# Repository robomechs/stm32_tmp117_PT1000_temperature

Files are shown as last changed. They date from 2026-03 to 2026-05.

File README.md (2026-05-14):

# STM32F103C8 BluePill USB Temperature Monitor

This project is a USB-connected temperature measurement setup for the STM32F103C8T6 **BluePill** board.

It combines:

- a **PT1000** analog sensor read by the STM32 ADC,
- a **TMP117** digital sensor connected over I2C,
- direct **USB CDC** communication from the BluePill to the PC,
- and a desktop **Python viewer** for live plotting, software filtering, and CSV logging.

The board connects to the PC **directly over USB** and enumerates as a virtual COM port. No separate USB-UART adapter is required.

## Project Overview

The firmware runs on an STM32F103C8-based BluePill board and streams temperature data over USB CDC.

Current default behavior:

- **PT1000** is sampled through the ADC at **1 kHz**
- the PT1000 ADC path is smoothed in firmware with a fixed-point LPF at about **10 Hz**
- PT1000 temperature is transmitted over USB at **20 Hz**
- **TMP117** is still polled in firmware at **20 Hz**
- TMP117 is **not filtered in firmware**
- TMP117 is **not sent by default**, but the code already supports switching to TMP117-only or both-sensors output

On the PC side, the included viewer can:

- connect to the USB virtual COM port,
- display live values,
- plot incoming data,
- apply a **software LPF** in the GUI,
- show or hide raw and filtered traces independently,
- and log data to CSV.

## Hardware

### Target MCU board

- **STM32F103C8T6 BluePill**

## Measurement Ranges

Reference specifications used here:

- [PT106052 / SA10200542 PT1000 listing](https://www.tme.com/ca/en/details/pt106052/temp-sensors-resistance-thermometers/cyntec-co-ltd/sa10200542/)
- [TI TMP117 product page](https://www.ti.com/product/TMP117)

### PT1000 channel

The PT1000 element used for this project is PT106052 / SA10200542 style: `Pt1000`, class B `0.12 %`, `3850 ppm/C`, with a specified operating range of approximately **-50 C to +500 C**.

This is the intended practical measurement range for the PT1000 channel.

The firmware uses a simple linear PT1000 approximation:

```text
R(T) = R0 * (1 + 0.00385 * T)
```

So the conversion is intentionally simple and integer-friendly for STM32F103. For better absolute accuracy across the full `-50...500 C` span, the next improvement would be a calibrated table or Callendar-Van Dusen conversion.

With the current divider value, the PT1000 range maps well into the 12-bit ADC input range:

| Temperature | Approx. PT1000 resistance | Approx. ADC code | Approx. ADC voltage at 3.3 V |
| --- | ---: | ---: | ---: |
| `-50 C` | `807.5 Ohm` | `2749` | `2.22 V` |
| `0 C` | `1000.0 Ohm` | `2550` | `2.06 V` |
| `25 C` | `1096.3 Ohm` | `2460` | `1.98 V` |
| `100 C` | `1385.0 Ohm` | `2226` | `1.79 V` |
| `500 C` | `2925.0 Ohm` | `1477` | `1.19 V` |

The ADC itself has much wider mathematical headroom, but the useful documented PT1000 range should be treated as **-50 C to +500 C** unless the sensor, mounting, wiring, and calibration are validated outside that range.

### TMP117 channel

The TMP117 channel is intended for the TMP117 operating range: **-55 C to +150 C**.

In the current firmware, TMP117 is polled at `20 Hz`, but the default USB stream sends PT1000 only. TMP117 output can be enabled in firmware with `USB_STREAM_MODE_TMP117` or `USB_STREAM_MODE_BOTH`.

### PT1000 connection

The PT1000 is connected as a simple divider from `3.3 V`:

- top resistor: **PT1000**
- bottom resistor: **1.65 kOhm**
- divider midpoint: `PA0 / ADC1_IN0`

Divider:

`3.3V -> PT1000 -> PA0 -> 1.65k -> GND`

The `1.65 kOhm` resistor was chosen to place the expected `-50...500 C` PT1000 resistance range comfortably inside the ADC range while keeping useful sensitivity over the whole span. It is not a common single resistor value, so it can be made from **two 3.3 kOhm resistors in parallel**:

```text
3.3k || 3.3k = 1.65k
```

The divider resistor is used directly by the firmware conversion. In [main.c](TMP117_stm32f103c8/Core/Src/main.c), the value is defined as `PT1000_BOTTOM_RESISTOR_MOHM`. It is stored in milliohms; the current nominal value is `1650000`, meaning `1650.000 Ohm`.

If better absolute accuracy is needed, measure the actual parallel resistance and put that value into `PT1000_BOTTOM_RESISTOR_MOHM` in milliohms.

If the PT1000 and the `1.65 kOhm` resistor are physically swapped during assembly, the firmware can be switched without rewiring. Set `PT1000_DIVIDER_PT1000_ON_TOP` to `0` in [main.c](TMP117_stm32f103c8/Core/Src/main.c). Default is `1`, meaning `3.3V -> PT1000 -> PA0 -> 1.65k -> GND`.

Swapping the divider mostly reverses the ADC slope. Sensitivity and self-heating are nearly the same because the same two resistors are still in series. With the correct define, measurements remain valid; with the wrong define, the temperature will be badly wrong.

### TMP117 connection

- `PB6` -> `I2C1_SCL`
- `PB7` -> `I2C1_SDA`
- default I2C address: `0x48`

Additional pins:

- `PB8` -> TMP117 `ALERT` input with external pull-up
- `PB9` -> TMP117 `ADD0` output, held low with external pull-down

### USB connection

The firmware uses the STM32 USB CDC device interface and appears on the PC as a virtual COM port.

Project-specific USB notes:

- `PB5` is used for the external USB reconnect/reset wiring
- D+ has an external `1.5 kOhm` pull-up to `3.3 V`
- the firmware generates a reconnect pulse during startup so the BluePill re-enumerates cleanly over USB

## Firmware

Firmware source is in:

- [TMP117_stm32f103c8](TMP117_stm32f103c8)

Main application file:

- [main.c](TMP117_stm32f103c8/Core/Src/main.c)

### Firmware data path

#### PT1000 path

- sampled by `ADC1` on `PA0`
- ADC timing tuned for slower, quieter sampling
- sampled at **1 kHz**
- filtered in firmware with fixed-point arithmetic
- converted to temperature in degrees Celsius
- sent over USB at **20 Hz**

#### TMP117 path

- read over `I2C1`
- polled at **20 Hz**
- kept in firmware for reference / comparison
- **not filtered in firmware**
- **not streamed by default**

### Default USB output

Current default build sends only PT1000:

```text
PT1000=24.875 C
```

With line ending on the wire:

```text
PT1000=24.875 C\r\n
```

### Other firmware output modes

The firmware can also send:

- TMP117 only
- both PT1000 and TMP117 in one line

These modes are selected in [main.c](TMP117_stm32f103c8/Core/Src/main.c) by the `USB_STREAM_MODE` define.

Typical options in the code:

- `USB_STREAM_MODE_PT1000`
- `USB_STREAM_MODE_TMP117`
- `USB_STREAM_MODE_BOTH`

Example combined line:

```text
PT1000=24.875 C TMP117=24.937 C
```

## Desktop Viewer

Viewer file:

- [temperature_viewer.pyw](temperature_viewer.pyw)

The viewer is intended for direct use with the BluePill USB CDC connection.

### Viewer features

- automatic COM port refresh
- connect/disconnect control
- compact COM names such as `COM3`
- live readout for PT1000 and TMP117
- plot view for one sensor or both sensors
- separate **Show raw** and **Show filtered** checkboxes
- software LPF modes:
  - `Off`
  - `EMA`
  - `SMA`
- adjustable visible X-axis window
- `Follow latest` mode
- `Auto Y`
- `Show all`
- `Reset view`
- `Clear plot`
- `Help` button with built-in usage notes
- CSV logging

### Important note about filtering

There are two different filtering layers in this project:

1. **Firmware PT1000 LPF**
   - applied on the MCU to the ADC path
   - fixed-point
   - currently about `10 Hz`

2. **Viewer software LPF**
   - applied inside the PC application
   - tunable in the UI
   - available for display, comparison, and CSV logging

TMP117 currently has **no firmware LPF**. In the viewer, TMP117 can still be filtered in software for visualization.

### Viewer input formats

The viewer accepts the current labeled firmware stream, for example:

```text
PT1000=24.875 C
```

or:

```text
PT1000=24.875 C TMP117=24.937 C
```

It also keeps compatibility with older single-value lines through the `Single line` selector in the UI.

### CSV logging

The viewer can save CSV with these columns:

```text
timestamp_s,pt1000_raw_c,pt1000_filtered_c,tmp117_raw_c,tmp117_filtered_c
```

## Python Requirements

The viewer uses:

- Python 3
- `PyQt6`
- `pyqtgraph`
- `pyserial`

Example install command:

```bash
pip install PyQt6 pyqtgraph pyserial
```

Run the viewer with:

```bash
py temperature_viewer.pyw
```

On Windows, you can also launch the `.pyw` file directly.

## Building the Firmware

This firmware project is based on an STM32CubeIDE-generated STM32F103 project.

Main project file:

- [TMP117_stm32f103c8.ioc](TMP117_stm32f103c8/TMP117_stm32f103c8.ioc)

### Recommended build flow

1. Open the project in **STM32CubeIDE**
2. Open the `.ioc` if needed
3. Let CubeIDE regenerate project files if required
4. Build the project for the **STM32F103C8T6 BluePill**
5. Flash it with your usual ST-Link workflow

### Command-line build

If the local `Debug` build directory already exists, the project can also be built with:

```bash
make -C TMP117_stm32f103c8/Debug all
```

Note:

- `Debug/` is gitignored
- in a fresh clone, it is normal to open the project in CubeIDE first so the build files are present locally

## Repository Layout

- [TMP117_stm32f103c8](TMP117_stm32f103c8) - STM32 firmware project
- [temperature_viewer.pyw](temperature_viewer.pyw) - desktop GUI viewer
- [TMP117_PCB](TMP117_PCB) - KiCad PCB project

Inside the PCB folder:

- KiCad source project is in [tmp117](TMP117_PCB/tmp117)
- [bom](TMP117_PCB/tmp117/bom) contains BOM-related output
- [manuf](TMP117_PCB/tmp117/manuf) contains manufacturing files

## Practical Usage

Typical workflow:

1. Flash the firmware to the **BluePill**
2. Connect the board to the PC via **USB**
3. Wait for the USB CDC virtual COM port to appear
4. Start [temperature_viewer.pyw](temperature_viewer.pyw)
5. Select the COM port
6. Click `Connect`
7. View live temperature, tune software LPF, and log CSV if needed

## Notes

- The repository ignores generated build outputs, Python cache files, KiCad local history, and KiCad backup archives.
- The current default USB stream is PT1000-only, which keeps the USB output simple for the viewer and logging workflow.
- TMP117 acquisition is still active in firmware, so enabling dual-sensor output later is straightforward.

## PT1000 Wiring Quick Reference

Use this connection for the PT1000 divider:

```text
BluePill 3V3 -> PT1000 -> PA0 / ADC1_IN0 -> 1.65k -> GND
```

This is the default firmware setting:

```c
#define PT1000_DIVIDER_PT1000_ON_TOP 1U
```

If the parts are swapped:

```text
BluePill 3V3 -> 1.65k -> PA0 / ADC1_IN0 -> PT1000 -> GND
```

use this firmware setting:

```c
#define PT1000_DIVIDER_PT1000_ON_TOP 0U
```

The bottom resistor may be either:

```text
single 1.65k resistor
```

or:

```text
two 3.3k resistors in parallel
```

Keep the ADC node connected only to `PA0`, the PT1000, and the bottom resistor. Do not connect the divider to `5 V`; the firmware assumes `3.3 V` ADC reference behavior.

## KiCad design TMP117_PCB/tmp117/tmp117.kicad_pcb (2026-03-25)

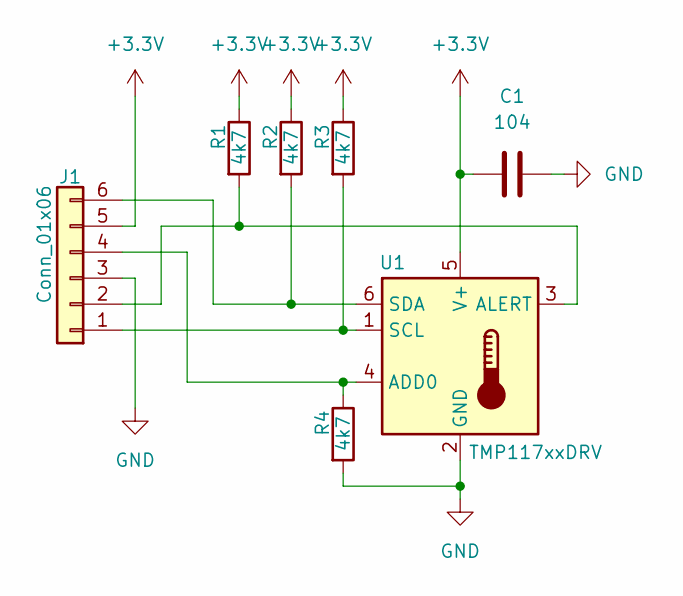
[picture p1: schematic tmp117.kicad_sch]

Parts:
C1: 104; C_1206_3216Metric
J1: Conn_01x06; Zhaoxing_VH_ZX-VH3.96-6PLT_1x06-1MP_P3.96mm_Vertical
R1, R2, R3, R4: 4k7; R_0805_2012Metric_Pad1.20x1.40mm_HandSolder
U1: TMP117xxDRV; WSON-6-1EP_2x2mm_P0.65mm_EP1x1.6mm

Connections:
+3.3V: C1.1, J1.5, R1.1, R2.1, R3.1, U1.5 (V+)
GND: C1.2, J1.3, R4.2, U1.2 (GND)
unnamed: J1.1, R3.2, U1.1 (SCL)
unnamed: J1.2, R1.2, U1.3 (ALERT)
unnamed: J1.4, R4.1, U1.4 (ADD0)
unnamed: J1.6, R2.2, U1.6 (SDA)

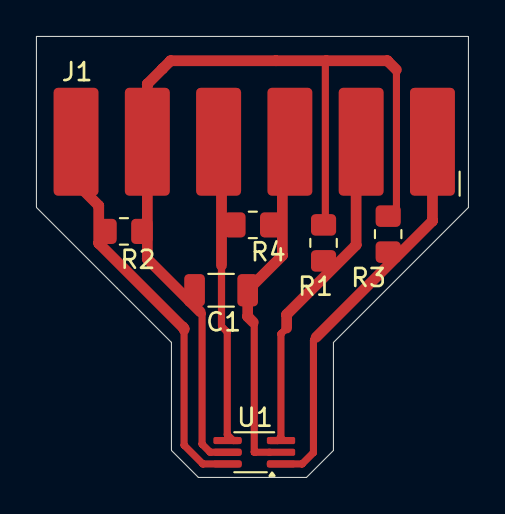
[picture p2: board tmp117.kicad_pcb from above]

Board: 2 copper layers, 24.0 x 24.5 mm, 7 parts (0 on the bottom side), 6 nets.

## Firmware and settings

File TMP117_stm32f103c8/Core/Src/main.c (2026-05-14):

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
/* Includes ------------------------------------------------------------------*/
#include "main.h"

/* USER CODE BEGIN Includes */
#include "usb_device.h"
#include "usbd_cdc_if.h"
#include <limits.h>
#include <stdio.h>

/* USER CODE END Includes */

/* USER CODE BEGIN PD */
#define TMP117_I2C_ADDRESS     (0x48U << 1)
#define TMP117_REG_TEMPERATURE 0x00U
#define TMP117_I2C_TIMEOUT_MS  50U
#define USB_RECONNECT_DELAY_MS 50U

#define PT1000_FILTER_SAMPLE_RATE_HZ        1000U
#define PT1000_USB_OUTPUT_RATE_HZ           20U
#define PT1000_OUTPUT_TICKS                 (PT1000_FILTER_SAMPLE_RATE_HZ / PT1000_USB_OUTPUT_RATE_HZ)
#define PT1000_FILTER_ALPHA_Q15             1937U /* fc ~= 10 Hz at fs = 1 kHz */
#define PT1000_ADC_FULL_SCALE_COUNTS        4095U
#define PT1000_DIVIDER_PT1000_ON_TOP        1U /* 1: 3V3-PT1000-A0-1.65k-GND, 0: 3V3-1.65k-A0-PT1000-GND */
#define PT1000_BOTTOM_RESISTOR_MOHM         1650000LL
#define PT1000_REFERENCE_RESISTANCE_MOHM    1000000LL
#define PT1000_ALPHA_PPM_PER_C              3850LL

#define USB_STREAM_MODE_PT1000              0U
#define USB_STREAM_MODE_TMP117              1U
#define USB_STREAM_MODE_BOTH                2U
#define USB_STREAM_MODE                     USB_STREAM_MODE_PT1000

/* USER CODE END PD */

ADC_HandleTypeDef hadc1;
I2C_HandleTypeDef hi2c1;
TIM_HandleTypeDef htim2;

/* USER CODE BEGIN PV */
static volatile uint8_t usb_frame_due = 0U;
static volatile uint8_t tmp117_sample_due = 0U;
static volatile uint16_t pt1000_filtered_adc_counts = 0U;
static uint8_t usb_tx_pending = 0U;
static uint8_t usb_tx_buffer[96];
static uint16_t usb_tx_length = 0U;
static uint8_t pt1000_filter_initialized = 0U;
static int32_t pt1000_filter_state_q15 = 0;
static int32_t latest_pt1000_milli_c = 0;
static int32_t latest_tmp117_milli_c = 0;
static uint8_t latest_tmp117_valid = 0U;

/* USER CODE END PV */

void SystemClock_Config(void);
static void MX_ADC1_Init(void);
static void MX_GPIO_Init(void);
static void MX_I2C1_Init(void);
static void MX_TIM2_Init(void);
/* USER CODE BEGIN PFP */
static void USB_ReconnectPulse(void);
static HAL_StatusTypeDef TMP117_ReadRawTemperature(int16_t *raw_temperature);
static int32_t TMP117_RawToMilliC(int16_t raw_temperature);
static HAL_StatusTypeDef PT1000_SampleAndFilter(void);
static int32_t PT1000_AdcToMilliC(uint16_t adc_counts);
static void QueuePT1000Frame(void);
static void QueueTMP117Frame(void);
static void QueueBothTemperaturesFrame(void);
static void QueueSelectedTemperatureFrame(void);
static void ServiceTemperatureStream(void);

/* USER CODE END PFP */

/**
  * @brief  The application entry point.
  * @retval int
  */
int main(void)
{

  /* MCU Configuration--------------------------------------------------------*/

  /* Reset of all peripherals, Initializes the Flash interface and the Systick. */
  HAL_Init();

  /* Configure the system clock */
  SystemClock_Config();

  /* Initialize all configured peripherals */
  MX_GPIO_Init();
  MX_ADC1_Init();
  MX_I2C1_Init();
  MX_TIM2_Init();
  /* USER CODE BEGIN 2 */
  if (HAL_ADCEx_Calibration_Start(&hadc1) != HAL_OK)
  {
    Error_Handler();
  }

  USB_ReconnectPulse();
  MX_USB_DEVICE_Init();

  if (HAL_TIM_Base_Start_IT(&htim2) != HAL_OK)
  {
    Error_Handler();
  }

  /* USER CODE END 2 */

  /* Infinite loop */
  /* USER CODE BEGIN WHILE */
  while (1)
  {
    /* USER CODE END WHILE */

    /* USER CODE BEGIN 3 */
    ServiceTemperatureStream();
  }
  /* USER CODE END 3 */
}

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
/* USER CODE BEGIN 4 */
void HAL_TIM_PeriodElapsedCallback(TIM_HandleTypeDef *htim)
{
  static uint16_t output_tick_divider = 0U;

  if (htim->Instance == TIM2)
  {
    (void)PT1000_SampleAndFilter();

    output_tick_divider++;
    if (output_tick_divider >= PT1000_OUTPUT_TICKS)
    {
      output_tick_divider = 0U;
      usb_frame_due = 1U;
      tmp117_sample_due = 1U;
    }
  }
}

static void USB_ReconnectPulse(void)
{
  HAL_GPIO_WritePin(USB_RESER_DP_1K5_GPIO_Port, USB_RESER_DP_1K5_Pin, GPIO_PIN_RESET);
  HAL_Delay(USB_RECONNECT_DELAY_MS);
  HAL_GPIO_WritePin(USB_RESER_DP_1K5_GPIO_Port, USB_RESER_DP_1K5_Pin, GPIO_PIN_SET);
  HAL_Delay(USB_RECONNECT_DELAY_MS);
}

static HAL_StatusTypeDef TMP117_ReadRawTemperature(int16_t *raw_temperature)
{
  uint8_t raw_data[2];

  if (HAL_I2C_Mem_Read(&hi2c1, TMP117_I2C_ADDRESS, TMP117_REG_TEMPERATURE,
                       I2C_MEMADD_SIZE_8BIT, raw_data, sizeof(raw_data),
                       TMP117_I2C_TIMEOUT_MS) != HAL_OK)
  {
    return HAL_ERROR;
  }

  *raw_temperature = (int16_t)(((uint16_t)raw_data[0] << 8) | raw_data[1]);
  return HAL_OK;
}

static int32_t TMP117_RawToMilliC(int16_t raw_temperature)
{
  return ((int32_t)raw_temperature * 1000) / 128;
}

static HAL_StatusTypeDef PT1000_SampleAndFilter(void)
{
  uint16_t raw_adc_counts;
  int32_t raw_adc_q15;

  if (HAL_ADC_Start(&hadc1) != HAL_OK)
  {
    return HAL_ERROR;
  }

  if (HAL_ADC_PollForConversion(&hadc1, 1U) != HAL_OK)
  {
    (void)HAL_ADC_Stop(&hadc1);
    return HAL_ERROR;
  }

  raw_adc_counts = (uint16_t)HAL_ADC_GetValue(&hadc1);
  (void)HAL_ADC_Stop(&hadc1);

  if (raw_adc_counts == 0U)
  {
    raw_adc_counts = 1U;
  }
  else if (raw_adc_counts >= PT1000_ADC_FULL_SCALE_COUNTS)
  {
    raw_adc_counts = PT1000_ADC_FULL_SCALE_COUNTS - 1U;
  }

  raw_adc_q15 = (int32_t)raw_adc_counts << 15;

  if (pt1000_filter_initialized == 0U)
  {
    pt1000_filter_state_q15 = raw_adc_q15;
    pt1000_filter_initialized = 1U;
  }
  else
  {
    pt1000_filter_state_q15 +=
        (int32_t)(((int64_t)(raw_adc_q15 - pt1000_filter_state_q15) * PT1000_FILTER_ALPHA_Q15) >> 15);
  }

  pt1000_filtered_adc_counts = (uint16_t)((pt1000_filter_state_q15 + (1L << 14)) >> 15);
  return HAL_OK;
}

static int32_t PT1000_AdcToMilliC(uint16_t adc_counts)
{
  uint32_t adc_counts_u32 = adc_counts;
  int64_t pt1000_resistance_mohm;
  int64_t milli_c;

  /*
   * Divider, default:
   * 3V3 --- PT1000 --- ADC input --- 1.65k --- GND
   *
   * Using Vref = VCC cancels the supply in the resistance calculation:
   * Rpt = Rbottom * (4095 - adc) / adc
   *
   * If the divider is physically swapped, set PT1000_DIVIDER_PT1000_ON_TOP
   * to 0 in the private defines above:
   * 3V3 --- 1.65k --- ADC input --- PT1000 --- GND
   * Rpt = Rtop * adc / (4095 - adc)
   *
   * Temperature uses the PT1000 alpha approximation:
   * R(T) = R0 * (1 + 0.00385 * T)
   */
  if (adc_counts_u32 == 0U)
  {
    adc_counts_u32 = 1U;
  }
  else if (adc_counts_u32 >= PT1000_ADC_FULL_SCALE_COUNTS)
  {
    adc_counts_u32 = PT1000_ADC_FULL_SCALE_COUNTS - 1U;
  }

#if PT1000_DIVIDER_PT1000_ON_TOP
  pt1000_resistance_mohm =
      (PT1000_BOTTOM_RESISTOR_MOHM * (PT1000_ADC_FULL_SCALE_COUNTS - adc_counts_u32) + (adc_counts_u32 / 2U)) /
      adc_counts_u32;
#else
  pt1000_resistance_mohm =
      (PT1000_BOTTOM_RESISTOR_MOHM * adc_counts_u32 +
       ((PT1000_ADC_FULL_SCALE_COUNTS - adc_counts_u32) / 2U)) /
      (PT1000_ADC_FULL_SCALE_COUNTS - adc_counts_u32);
#endif
  milli_c = ((pt1000_resistance_mohm - PT1000_REFERENCE_RESISTANCE_MOHM) * 1000LL) /
            PT1000_ALPHA_PPM_PER_C;

  if (milli_c > INT32_MAX)
  {
    return INT32_MAX;
  }
  if (milli_c < INT32_MIN)
  {
    return INT32_MIN;
  }

  return (int32_t)milli_c;
}

static void QueuePT1000Frame(void)
{
  int length;
  uint32_t absolute_milli_c;

  absolute_milli_c = (uint32_t)((latest_pt1000_milli_c < 0) ? -latest_pt1000_milli_c : latest_pt1000_milli_c);
  length = snprintf((char *)usb_tx_buffer, sizeof(usb_tx_buffer),
                    "PT1000=%s%lu.%03lu C\r\n",
                    (latest_pt1000_milli_c < 0) ? "-" : "",
                    (unsigned long)(absolute_milli_c / 1000U),
                    (unsigned long)(absolute_milli_c % 1000U));

  if (length < 0)
  {
    return;
  }
  if ((size_t)length >= sizeof(usb_tx_buffer))
  {
    length = (int)sizeof(usb_tx_buffer) - 1;
  }
  usb_tx_length = (uint16_t)length;
  usb_tx_pending = 1U;
}

static void QueueTMP117Frame(void)
{
  int length;
  uint32_t absolute_milli_c;

  if (latest_tmp117_valid == 0U)
  {
    usb_tx_length = (uint16_t)snprintf((char *)usb_tx_buffer, sizeof(usb_tx_buffer),
                                       "TMP117=error\r\n");
    usb_tx_pending = 1U;
    return;
  }

  absolute_milli_c = (uint32_t)((latest_tmp117_milli_c < 0) ? -latest_tmp117_milli_c
                                                             : latest_tmp117_milli_c);

  length = snprintf((char *)usb_tx_buffer, sizeof(usb_tx_buffer),
                    "TMP117=%s%lu.%03lu C\r\n",
                    (latest_tmp117_milli_c < 0) ? "-" : "",
                    (unsigned long)(absolute_milli_c / 1000U),
                    (unsigned long)(absolute_milli_c % 1000U));

  if (length < 0)
  {
    return;
  }

  if ((size_t)length >= sizeof(usb_tx_buffer))
  {
    length = (int)sizeof(usb_tx_buffer) - 1;
  }

  usb_tx_length = (uint16_t)length;
  usb_tx_pending = 1U;
}

static void QueueBothTemperaturesFrame(void)
{
  int length;
  uint32_t pt1000_absolute_milli_c;
  uint32_t tmp117_absolute_milli_c;

  if (latest_tmp117_valid == 0U)
  {
    pt1000_absolute_milli_c =
        (uint32_t)((latest_pt1000_milli_c < 0) ? -latest_pt1000_milli_c : latest_pt1000_milli_c);
    length = snprintf((char *)usb_tx_buffer, sizeof(usb_tx_buffer),
                      "PT1000=%s%lu.%03lu C TMP117=error\r\n",
                      (latest_pt1000_milli_c < 0) ? "-" : "",
                      (unsigned long)(pt1000_absolute_milli_c / 1000U),
                      (unsigned long)(pt1000_absolute_milli_c % 1000U));
  }
  else
  {
    pt1000_absolute_milli_c =
        (uint32_t)((latest_pt1000_milli_c < 0) ? -latest_pt1000_milli_c : latest_pt1000_milli_c);
    tmp117_absolute_milli_c =
        (uint32_t)((latest_tmp117_milli_c < 0) ? -latest_tmp117_milli_c : latest_tmp117_milli_c);

    length = snprintf((char *)usb_tx_buffer, sizeof(usb_tx_buffer),
                      "PT1000=%s%lu.%03lu C TMP117=%s%lu.%03lu C\r\n",
                      (latest_pt1000_milli_c < 0) ? "-" : "",
                      (unsigned long)(pt1000_absolute_milli_c / 1000U),
                      (unsigned long)(pt1000_absolute_milli_c % 1000U),
                      (latest_tmp117_milli_c < 0) ? "-" : "",
                      (unsigned long)(tmp117_absolute_milli_c / 1000U),
                      (unsigned long)(tmp117_absolute_milli_c % 1000U));
  }

  if (length < 0)
  {
    return;
  }

  if ((size_t)length >= sizeof(usb_tx_buffer))
  {
    length = (int)sizeof(usb_tx_buffer) - 1;
  }

  usb_tx_length = (uint16_t)length;
  usb_tx_pending = 1U;
}

static void QueueSelectedTemperatureFrame(void)
{
  /*
   * USB stream selection:
   * - USB_STREAM_MODE_PT1000 = send only PT1000 temperature
   * - USB_STREAM_MODE_TMP117 = send only TMP117 temperature
   * - USB_STREAM_MODE_BOTH   = send both sensors in one line (current default)
   *
   * Change USB_STREAM_MODE in the private defines section above.
   * The PC viewer applies its own tunable LPF in software.
   */
  switch (USB_STREAM_MODE)
  {
    case USB_STREAM_MODE_TMP117:
      QueueTMP117Frame();
      break;

    case USB_STREAM_MODE_BOTH:
      QueueBothTemperaturesFrame();
      break;

    case USB_STREAM_MODE_PT1000:
    default:
      QueuePT1000Frame();
      break;
  }
}

static void ServiceTemperatureStream(void)
{
  uint8_t run_usb_frame = 0U;
  uint8_t run_tmp117_measurement = 0U;
  uint16_t filtered_adc_counts;

  __disable_irq();
  if (tmp117_sample_due != 0U)
  {
    tmp117_sample_due = 0U;
    run_tmp117_measurement = 1U;
  }

  if ((usb_tx_pending == 0U) && (usb_frame_due != 0U))
  {
    usb_frame_due = 0U;
    run_usb_frame = 1U;
  }
  filtered_adc_counts = pt1000_filtered_adc_counts;
  __enable_irq();

  if (run_tmp117_measurement != 0U)
  {
    int16_t raw_temperature;

    if (TMP117_ReadRawTemperature(&raw_temperature) == HAL_OK)
    {
      latest_tmp117_milli_c = TMP117_RawToMilliC(raw_temperature);
      latest_tmp117_valid = 1U;
    }
    else
    {
      latest_tmp117_valid = 0U;
    }
  }

  if (run_usb_frame != 0U)
  {
    latest_pt1000_milli_c = PT1000_AdcToMilliC(filtered_adc_counts);
    QueueSelectedTemperatureFrame();
  }

  if ((usb_tx_pending != 0U) && (CDC_Transmit_FS(usb_tx_buffer, usb_tx_length) == USBD_OK))
  {
    usb_tx_pending = 0U;
  }
}

/* USER CODE END 4 */
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


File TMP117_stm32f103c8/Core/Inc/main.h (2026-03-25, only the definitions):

#define PT1000_ADC_Pin GPIO_PIN_0
#define PT1000_ADC_GPIO_Port GPIOA
#define USB_RESER_DP_1K5_Pin GPIO_PIN_5
#define USB_RESER_DP_1K5_GPIO_Port GPIOB
#define ALERT_Pin GPIO_PIN_8
#define ALERT_GPIO_Port GPIOB
#define ADD0_Pin GPIO_PIN_9
#define ADD0_GPIO_Port GPIOB

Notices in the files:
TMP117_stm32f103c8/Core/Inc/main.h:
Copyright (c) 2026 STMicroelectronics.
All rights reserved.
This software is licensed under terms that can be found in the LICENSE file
